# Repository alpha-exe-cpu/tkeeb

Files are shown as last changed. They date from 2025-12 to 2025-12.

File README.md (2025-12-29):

# TKEEB
---
So I've made a fully custom 88-key mechanical keyboard powered by the Raspberry Pi Pico (RP2040), running KMK Firmware.
The layout is a standard TKL-style matrix, and I added an EC11 Rotary Encoder for volume control, per-key RGB lighting, and a 0.96" SSD1306 I²C OLED display which will show the real-time clock + date.

## Hardware Overview

### Components
- Raspberry Pi Pico (RP2040)
- 88x Mechanical Switches (Kailh Hotswap Sockets)
- 1× EC11 Rotary Encoder (with Push Switch)
- 0.96" SSD1306 OLED (128×64, I²C)
- 88× WS2812B RGB LEDs (NeoPixels)
- 470µF Tantalum Capacitor (Case D) & 470Ω Resistor (for power stability)

> **Design Note:** I am currently upgrading the LED specification from the standard 5050 package to the compact **2020 form factor**. This optimization ensures superior mechanical clearance between the PCB surface and the hotswap sockets, allowing for a flush, high-density assembly without compromising RGB brightness.

### Schematic


### PCB


### 3D Render (Assembled)


### 3D Render (without PCB)


### 3D Render (Top Plate - Top)


### 3D Render (Top Plate - Bottom)


### 3D Render (Bottom Base)


### 3D Render (Knob)


## Firmware

The keyboard runs on **KMK Firmware**, which is a lightweight Python-based keyboard firmware stored directly on the device’s flash.
Because of the custom matrix routing used, the **keys will appear scrambled** when the keyboard is first plugged in. This is expected behavior.
I integrated **Vial** support (GUID: `8f2e4a1b-9c3d-4e5f-b6a7-0d9e8c7b6a51`) to handle this. You simply open [Vial.rocks](https://vial.rocks), use the Matrix Tester to identify the switches, and drag-and-drop the correct characters to remap them instantly without editing code.

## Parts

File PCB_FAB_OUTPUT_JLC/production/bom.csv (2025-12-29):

Designator |  | Footprint | Value | LCSC Part #
A1 | RaspberryPi_Pico_Common_Unspecified | 1 | RaspberryPi_Pico | C7203002
C1 | CP_EIA-7343-31_Kemet-D | 1 | 470uF | C561862
D1, D10, D11, D12, D13, D14, D15, D16, D17, D18, D19, D2, D20, D21, D22, D23, D24, D25, D26, D27, D28, D29, D3, D30, D31, D32, D33, D34, D35, D36, D37, D38, D39, D4, D40, D41, D42, D43, D44, D45, D46, D47, D48, D49, D5, D50, D51, D52, D53, D54, D55, D56, D57, D58, D59, D6, D60, D61, D62, D63, D64, D65, D66, D67, D68, D69, D7, D70, D71, D72, D73, D74, D75, D76, D77, D78, D79, D8, D80, D81, D82, D83, D84, D85, D86, D87, D88, D9 | D_DO-35_SOD27_P7.62mm_Horizontal | 88 | 1N4148 | C85057
D100, D101, D102, D103, D104, D105, D106, D107, D108, D109, D110, D111, D112, D113, D114, D115, D116, D117, D118, D119, D120, D121, D122, D123, D124, D125, D126, D127, D128, D129, D130, D131, D132, D133, D134, D135, D136, D137, D138, D139, D140, D141, D142, D143, D144, D145, D146, D147, D148, D149, D150, D151, D152, D153, D154, D155, D156, D157, D158, D159, D160, D161, D162, D163, D164, D165, D166, D167, D168, D169, D170, D171, D172, D173, D174, D175, D176, D177, D178, D179, D92, D93, D94, D95, D96, D97, D98, D99 | LED_WS2812B_PLCC4_5.0x5.0mm_P3.2mm | 88 | WS2812B | C2761795
J1 | SSD1306-0.91-OLED-4pin-128x32 | 1 | Conn_01x04_Pin | DNP
R1 | 805 | 1 | 470Ω | C20162961
SW1, SW10, SW11, SW12, SW13, SW14, SW15, SW16, SW17, SW18, SW19, SW2, SW20, SW21, SW22, SW23, SW24, SW25, SW26, SW27, SW28, SW29, SW3, SW30, SW31, SW32, SW33, SW34, SW35, SW36, SW37, SW38, SW39, SW4, SW40, SW41, SW42, SW43, SW44, SW45, SW46, SW47, SW48, SW49, SW5, SW50, SW51, SW52, SW53, SW54, SW55, SW56, SW57, SW58, SW59, SW6, SW60, SW61, SW62, SW7, SW71, SW72, SW73, SW74, SW75, SW76, SW77, SW78, SW79, SW8, SW80, SW81, SW9 | MX-Hotswap-1U | 73 | SW_Push | DNP
SW63, SW64, SW65, SW67, SW68, SW69, SW70 | MX-Hotswap-1.25U | 7 | SW_Push | DNP
SW66 | MX-Hotswap-6.25U | 1 | SW_Push | DNP
SW82, SW87 | MX-Hotswap-2.25U | 2 | SW_Push | DNP
SW83, SW84 | MX-Hotswap-1.5U | 2 | SW_Push | DNP
SW85 | MX-Hotswap-1.75U | 1 | SW_Push | DNP
SW86 | MX-Hotswap-2U | 1 | SW_Push | DNP
SW88 | MX-Hotswap-2.75U | 1 | SW_Push | DNP
SW89 | RotaryEncoder_Alps_EC11E-Switch_Vertical_H20mm | 1 | RotaryEncoder_Switch | DNP

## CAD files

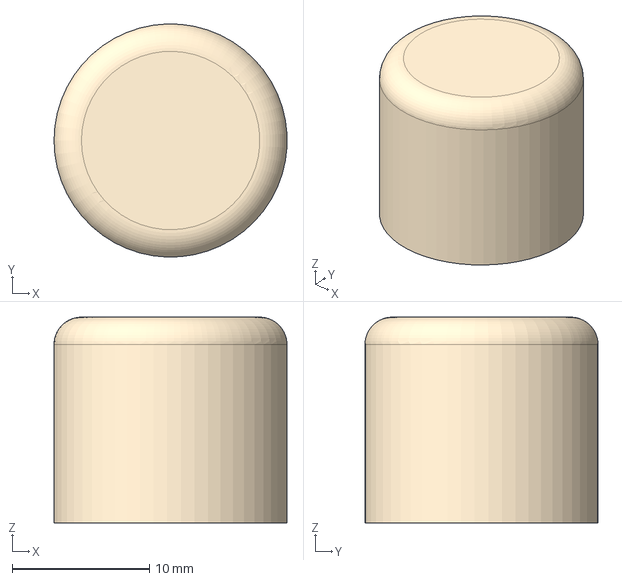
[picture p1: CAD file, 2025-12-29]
CAD_FAB_Output/TKEEB_KNOB.step
17.0 x 17.0 x 15.0 mm

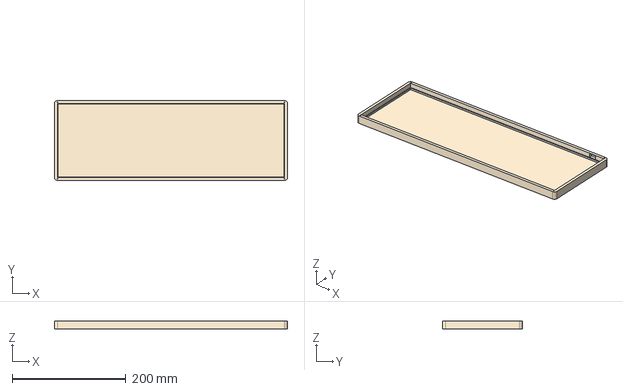
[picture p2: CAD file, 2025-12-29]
CAD_FAB_Output/TKEEB_BASE.step
410.0 x 140.7 x 14.0 mm

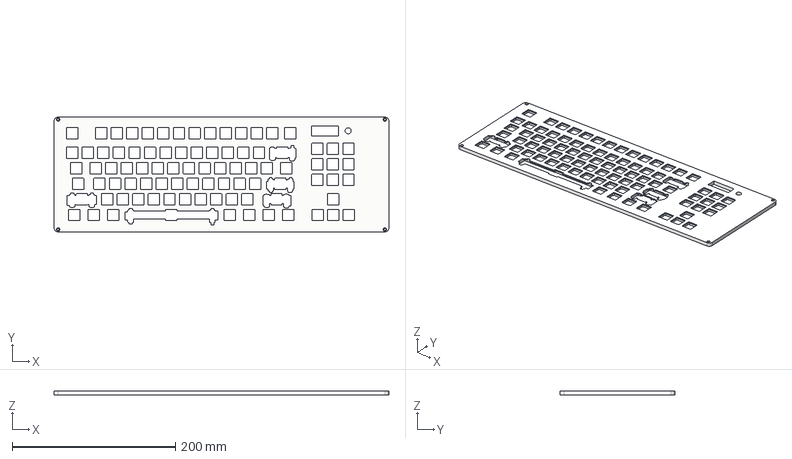
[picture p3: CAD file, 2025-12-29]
CAD_FAB_Output/TKEEB_TOP.step
410.0 x 140.7 x 5.00 mm

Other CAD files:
CAD_ADeskFus/tkeeb.f3z

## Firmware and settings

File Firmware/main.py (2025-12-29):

print("TKeeb is starting...")
import board
import busio
import time
import rtc

from kmk.kmk_keyboard import KMKKeyboard
from kmk.keys import KC
from kmk.scanners import DiodeOrientation
from kmk.scanners.digitalio import DigitalIO
from kmk.modules.layers import Layers
from kmk.modules.encoder import EncoderHandler
from kmk.extensions.media_keys import MediaKeys
from kmk.modules.vial import Vial
from kmk.extensions.RGB import RGB, AnimationModes
from kmk.extensions.peg_oled_display import Oled, OledDisplayMode, OledData

# --- 1. My Keyboard & Matrix Setup ---
keyboard = KMKKeyboard()

# I am defining the Main Matrix (88 Keys)
# Rows: GP0-GP7, Cols: GP8-GP18
matrix_scanner = DiodeOrientation(
    col_pins=(board.GP8, board.GP9, board.GP10, board.GP11, 
              board.GP12, board.GP13, board.GP14, board.GP15, 
              board.GP16, board.GP17, board.GP18),
    row_pins=(board.GP0, board.GP1, board.GP2, board.GP3, 
              board.GP4, board.GP5, board.GP6, board.GP7),
    diode_orientation=DiodeOrientation.COL2ROW
)

# I configured the Encoder Button (GP26) as a Direct Pin here.
# This allows my button to work even though it's not in the main grid.
direct_scanner = DigitalIO(
    pins=(board.GP26,),
    pull_up=True  # Switch connects Pin -> GND
)

# I combine both scanners so the keyboard sees all 89 keys
keyboard.matrix = [matrix_scanner, direct_scanner]

# --- 2. Modules & Extensions ---
keyboard.modules.append(Layers())
keyboard.extensions.append(MediaKeys())

# Vial Integration (For my dynamic remapping)
vial = Vial()
vial.vial_keyboard_uid = bytearray.fromhex("8f2e4a1b-9c3d-4e5f-b6a7-0d9e8c7b6a51")
vial.vial_unlock_combo = (KC.LSHIFT, KC.RSHIFT, KC.UP)
keyboard.modules.append(vial)

# --- 3. Rotary Encoder (Rotation) ---
# My Pins: A=GP21, B=GP22
encoder_handler = EncoderHandler()
encoder_handler.pins = ((board.GP21, board.GP22, None, False),)
# Mapping Rotation: [Layer 0: (Volume Down, Volume Up)]
encoder_handler.map = [ ((KC.VOLD, KC.VOLU),) ]
keyboard.modules.append(encoder_handler)

# --- 4. RGB Lighting (GP27) ---
rgb = RGB(
    pixel_pin=board.GP27,
    num_pixels=88,
    val_limit=150,     # I set a safety brightness limit (0-255)
    hue_default=0,
    sat_default=255,
    val_default=100,
    animation_mode=AnimationModes.BREATHING
)
keyboard.extensions.append(rgb)

# --- 5. OLED Display (Time & Date) ---
# Pins: SCL=GP19, SDA=GP20
# 'adafruit_display_text', 'adafruit_ssd1306', 'adafruit_bus_device' in /lib is needed here.

# Custom Class I wrote to display Time
class TimeDisplay(OledData):
    def __init__(self):
        self._rtc = rtc.RTC()
        # Set Default Time: YYYY, M, D, H, M, S, W, Y, DST
        # Note: Time resets on power loss since I don't have a battery backup yet.
        self._rtc.datetime = time.struct_time((2025, 1, 1, 12, 00, 00, 2, 1, -1))

    def text(self, keyboard):
        t = self._rtc.datetime
        return f"{t.tm_hour:02}:{t.tm_min:02}:{t.tm_sec:02}\n{t.tm_year}-{t.tm_mon:02}-{t.tm_mday:02}"

# Initialize OLED
try:
    oled_ext = Oled(
        OledData(image={0: TimeDisplay()}),
        toDisplay=OledDisplayMode.TXT,
        flip=False,
    )
    # Force I2C pins in case auto-detect fails on my setup
    oled_ext._i2c = busio.I2C(board.GP19, board.GP20)
    keyboard.extensions.append(oled_ext)
except Exception as e:
    print("OLED Error:", e)

# --- 6. Keymap ---
# There are 88 Matrix Keys + 1 Encoder Button so it's 89 items in the map
# Cuz I am using Vial, these are just placeholders. 
# I will use vial.rocks to assign the real keys later.

keyboard.keymap = [
    [
        # --- My 88 Matrix Keys ---
        KC.A, KC.B, KC.C, KC.D, KC.E, KC.F, KC.G, KC.H, KC.I, KC.J, KC.K,
        KC.L, KC.M, KC.N, KC.O, KC.P, KC.Q, KC.R, KC.S, KC.T, KC.U, KC.V,
        KC.W, KC.X, KC.Y, KC.Z, KC.N1, KC.N2, KC.N3, KC.N4, KC.N5, KC.N6,
        KC.N7, KC.N8, KC.N9, KC.N0, KC.ENT, KC.ESC, KC.BSPC, KC.TAB, KC.SPC, KC.MINS,
        KC.EQL, KC.LBRC, KC.RBRC, KC.BSLS, KC.SCLN, KC.QUOT, KC.GRV, KC.COMM, KC.DOT, KC.SLSH,
        KC.CAPS, KC.F1, KC.F2, KC.F3, KC.F4, KC.F5, KC.F6, KC.F7, KC.F8, KC.F9,
        KC.F10, KC.F11, KC.F12, KC.PSCR, KC.SLCK, KC.PAUS, KC.INS, KC.HOME, KC.PGUP, KC.DEL,
        KC.END, KC.PGDN, KC.RGHT, KC.LEFT, KC.DOWN, KC.UP, KC.NLCK, KC.PSLS, KC.PAST, KC.PMNS,
        KC.PPLS, KC.PENT, KC.PDOT, KC.P0, KC.P1, KC.P2, KC.P3, KC.P4,
        
        # --- My Encoder Switch (Key #89) ---
        KC.MUTE 
    ]
]

if __name__ == '__main__':
    keyboard.go()
